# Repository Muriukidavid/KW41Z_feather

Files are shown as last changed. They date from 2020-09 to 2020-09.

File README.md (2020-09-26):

# KW41Z_feather 
 
A feather form factor for BLE, ZigBee or Thread node based on the NXP MKW41Z wireless microcontroller. This is work in progress and a completely untested design as at this point. 

## Preview

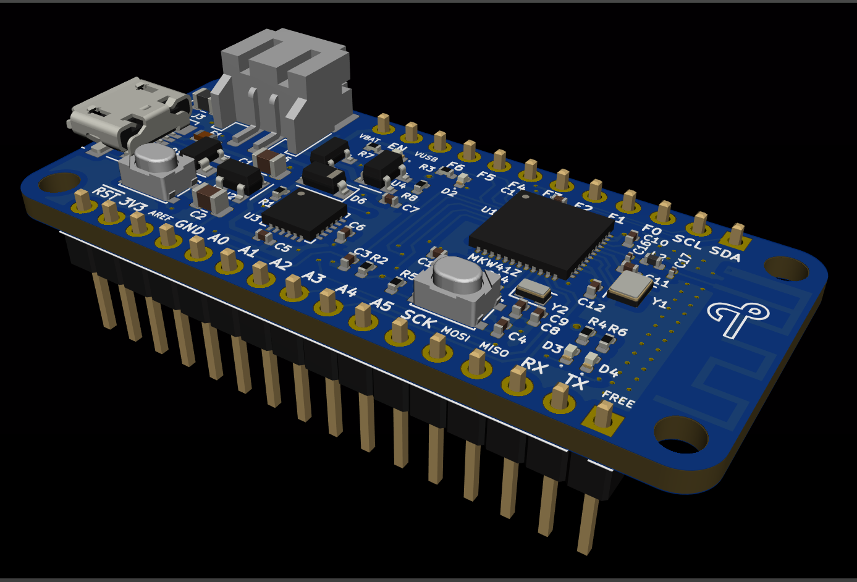
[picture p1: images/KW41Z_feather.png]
PCB Design


## Features 

* Feather header pins (custom mapping due to limited MCU pins)
* NXP MKW41Z Wireless MCU With a PCB antennae
* SWD Debug (using some of the feather header pins)
* USB to UART (CP2104) connected to the MCU UART terminal
* LiPo battery charger (SL4054ST25P) with a standard battery connector
* On board 5V to 3.3V regulator
* RTC oscillator
* Reset and user buttons
* Indicator LEDs (One user LED, two BLE activity LEDs) 

## Planned 

* Add U.FL connector for external antennae with a series selection resistor
* Add on-board SD card connector (back side)

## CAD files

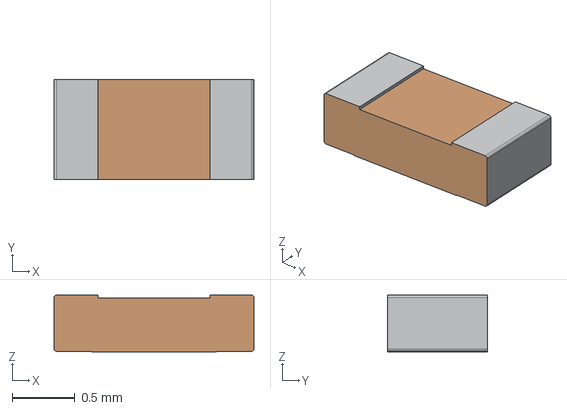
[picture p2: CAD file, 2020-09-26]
3D_Models/SF-0603F.step
1.60 x 0.8 x 0.455 mm

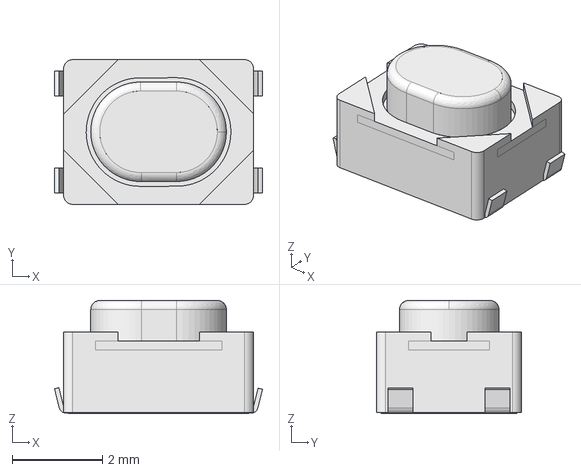
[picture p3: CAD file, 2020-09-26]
3D_Models/PTS810.step
4.60 x 3.20 x 2.50 mm

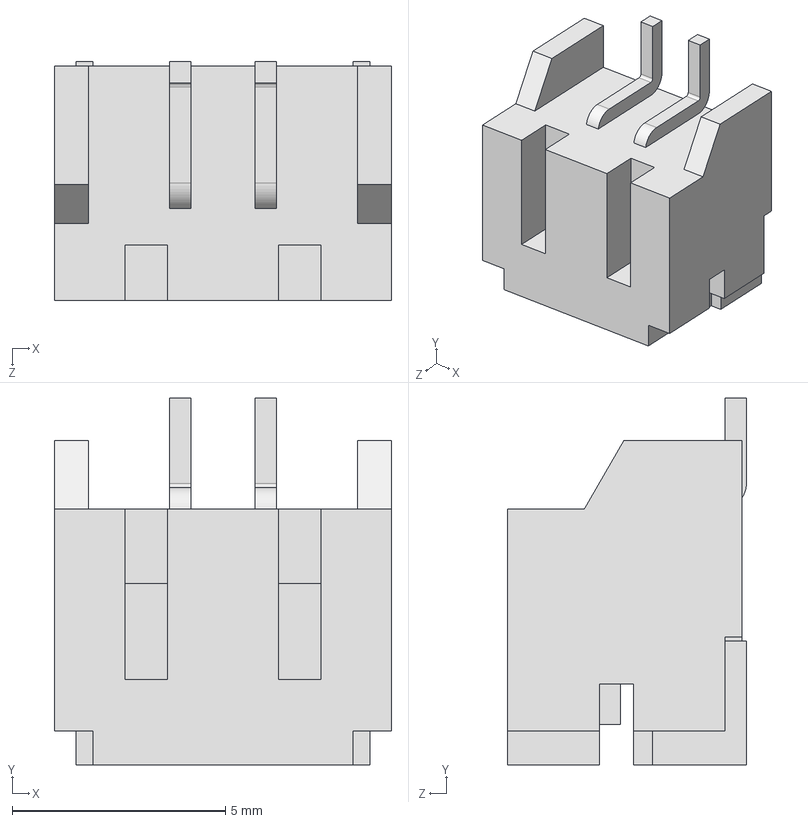
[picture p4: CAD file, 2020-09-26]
3D_Models/S2B-PH-SM4-TB.step
7.90 x 8.60 x 5.60 mm

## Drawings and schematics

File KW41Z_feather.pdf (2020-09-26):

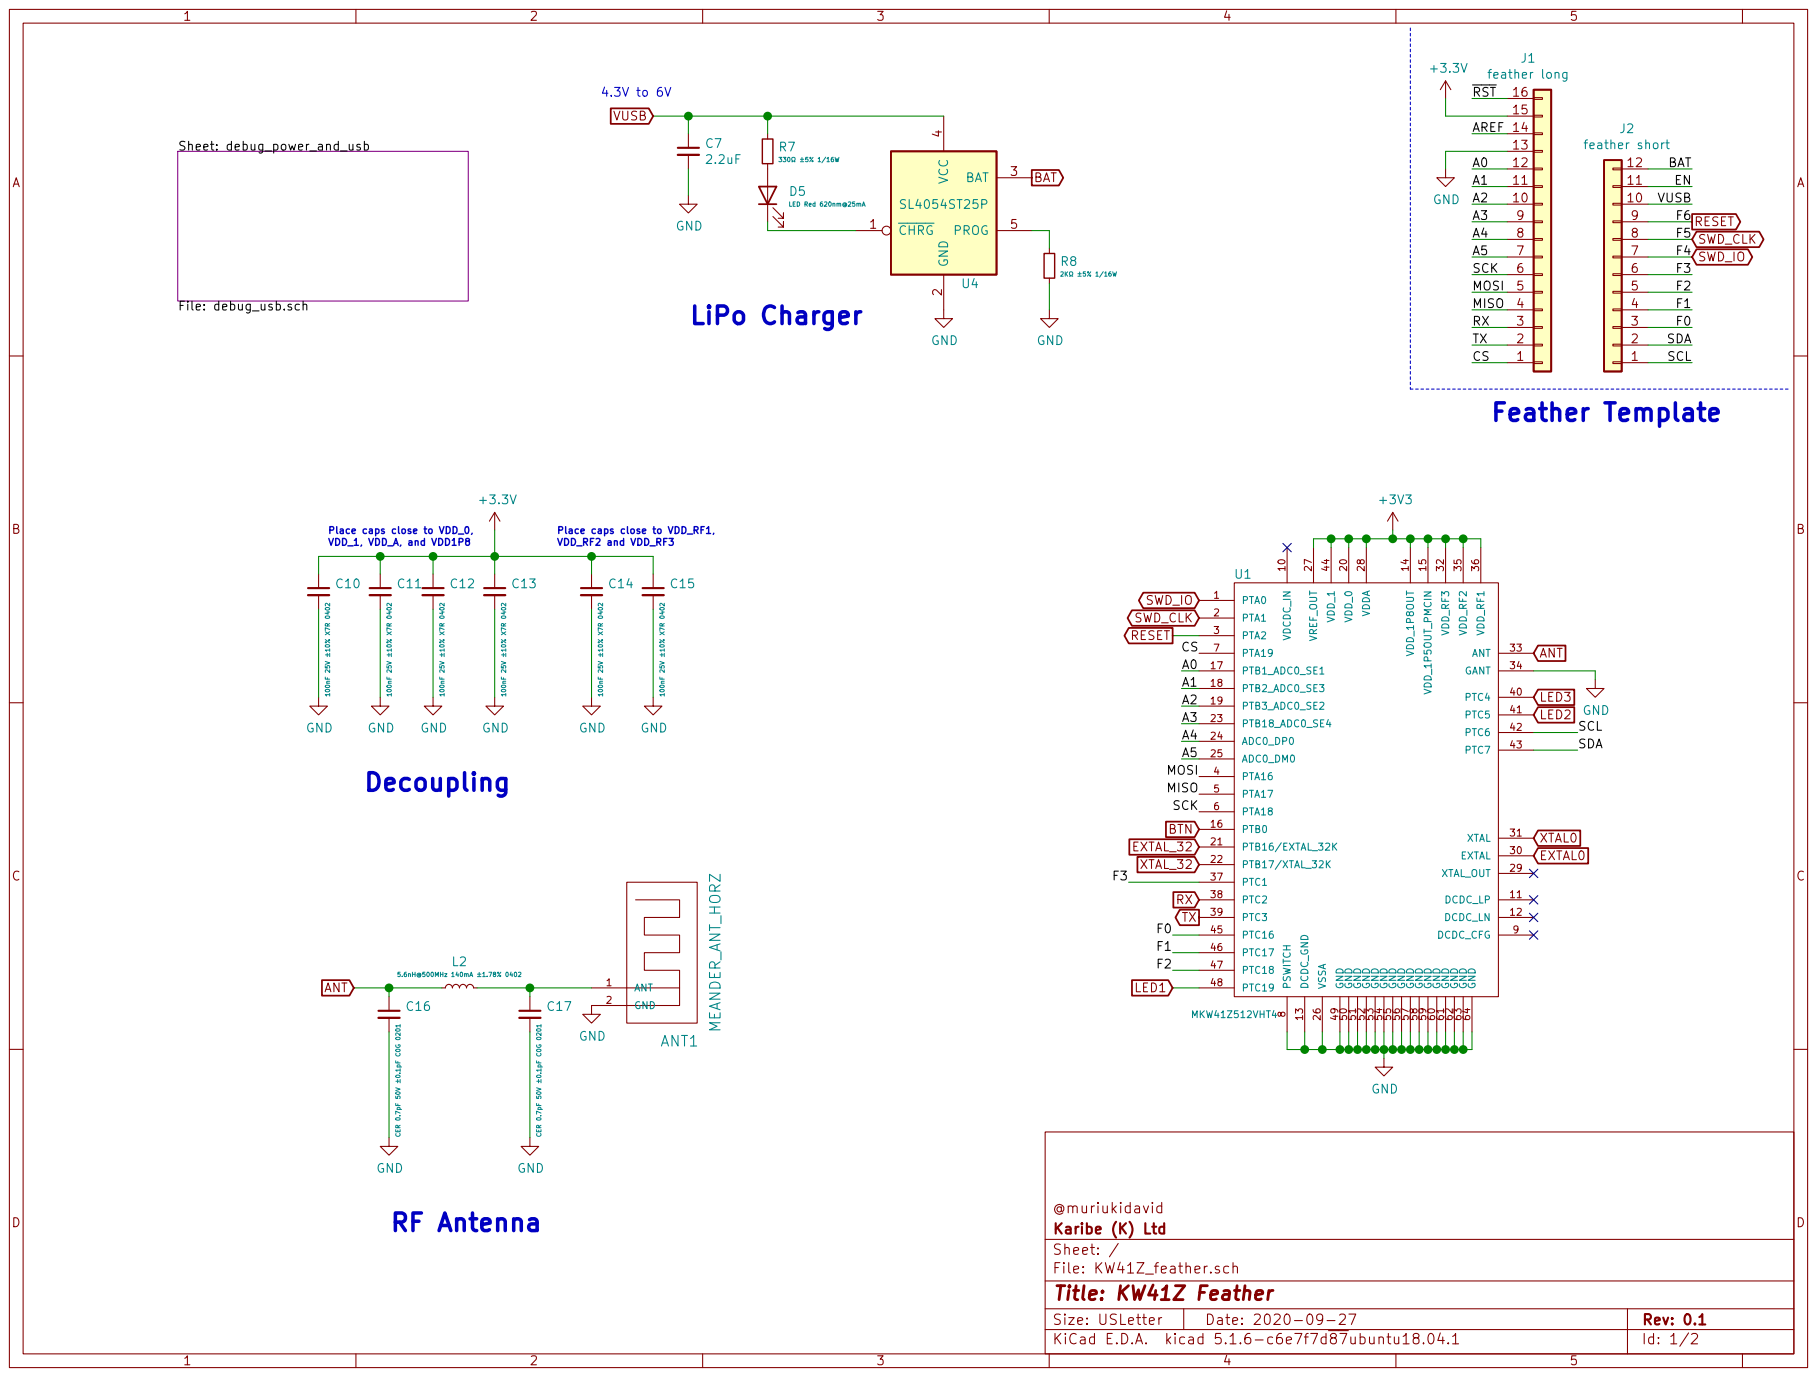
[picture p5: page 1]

RST AREF MOSI SCK

Place caps close to VDD_RF1, VDD_RF2 and VDD_RF3 Place caps close to VDD_0, VDD_1, VDD_A, and VDD1P8 Decoupling

@muriukidavid
File: KW41Z_feather.sch Sheet: / Karibe (K) Ltd

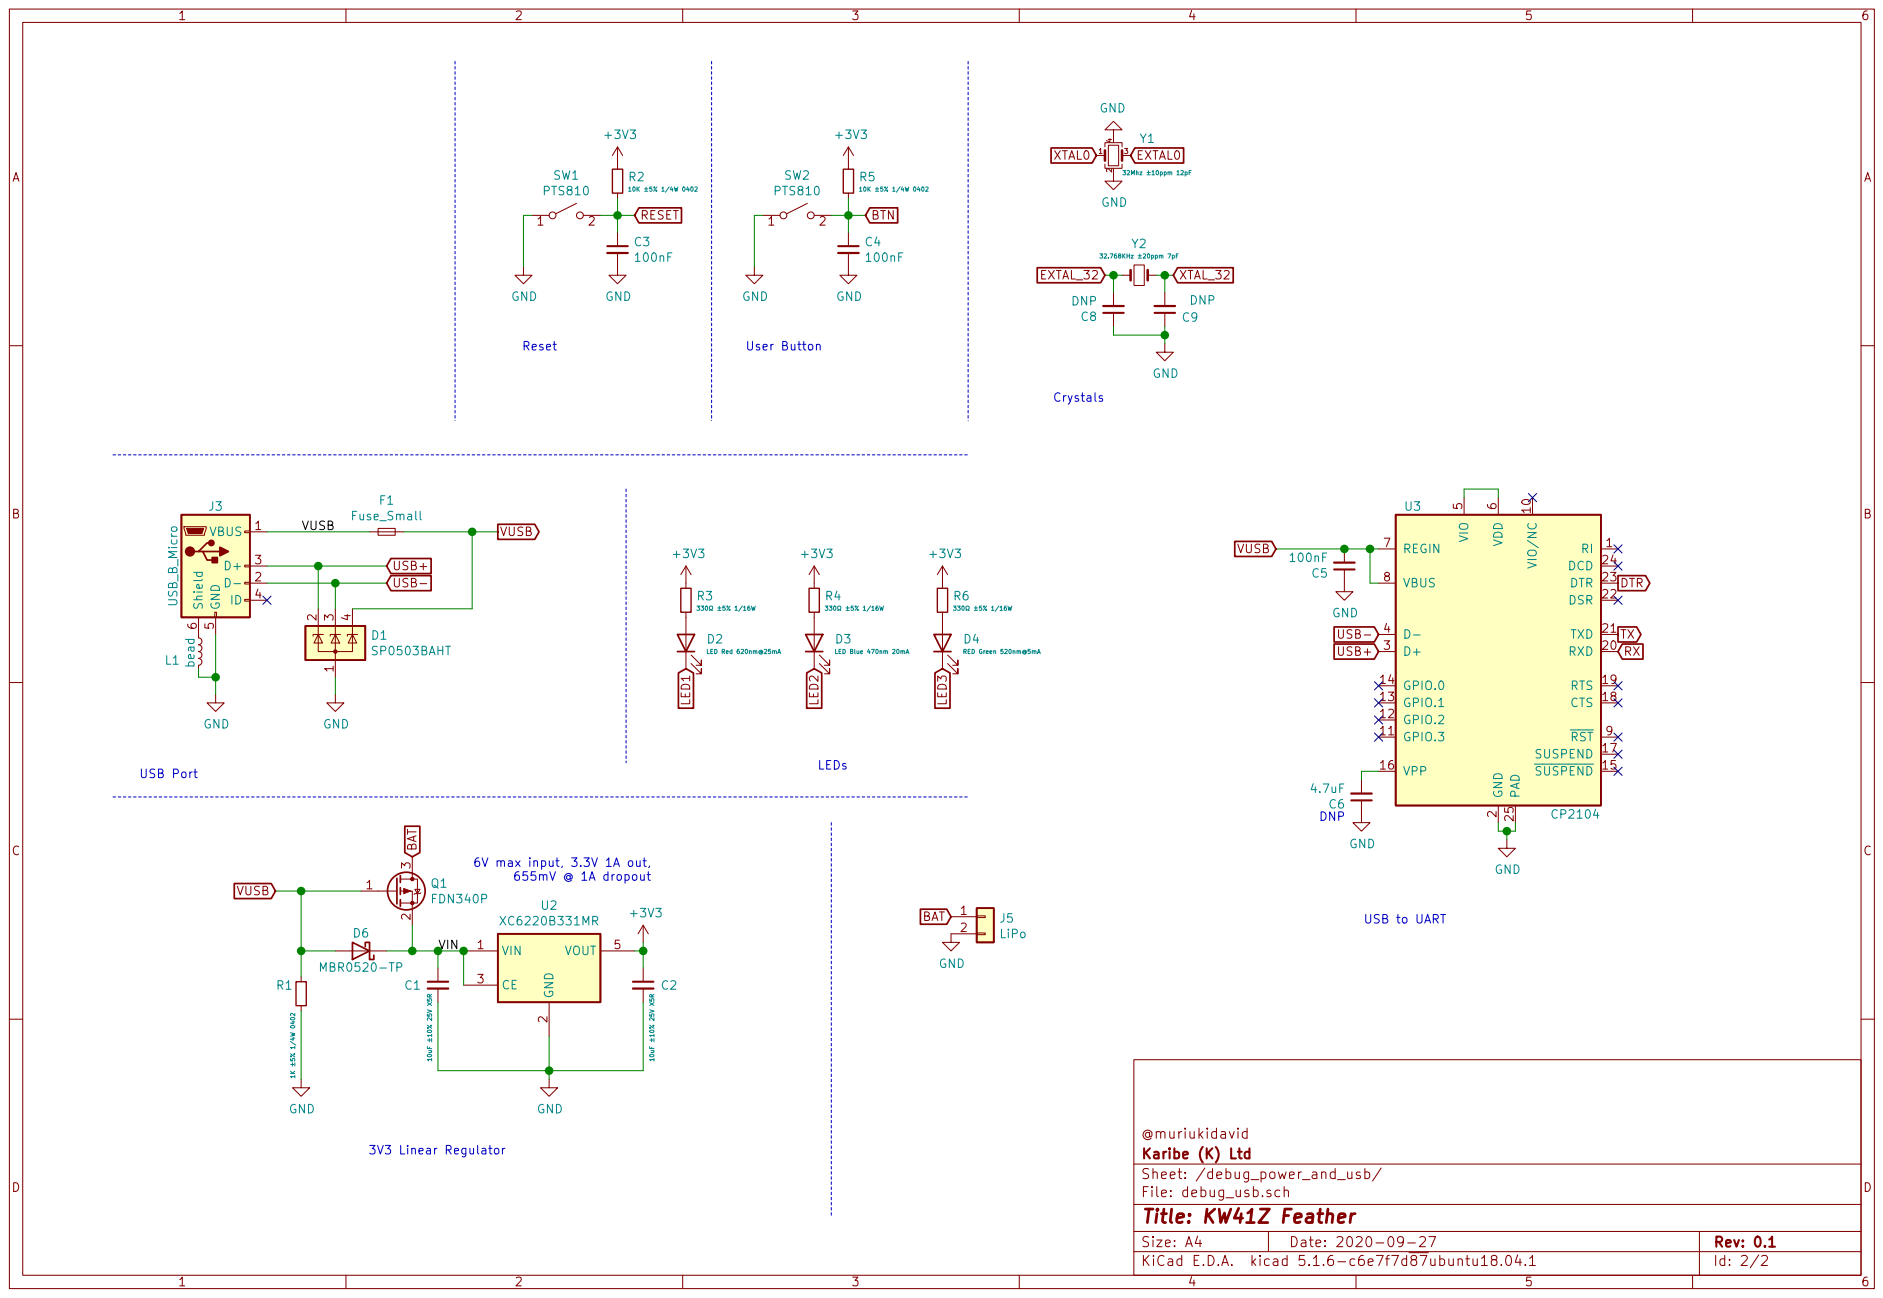
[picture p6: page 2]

2 RXD 20 TXD 21 DSR 22 DTR 23 DCD 24 PAD 25 D+ 3 D- 4 VIO

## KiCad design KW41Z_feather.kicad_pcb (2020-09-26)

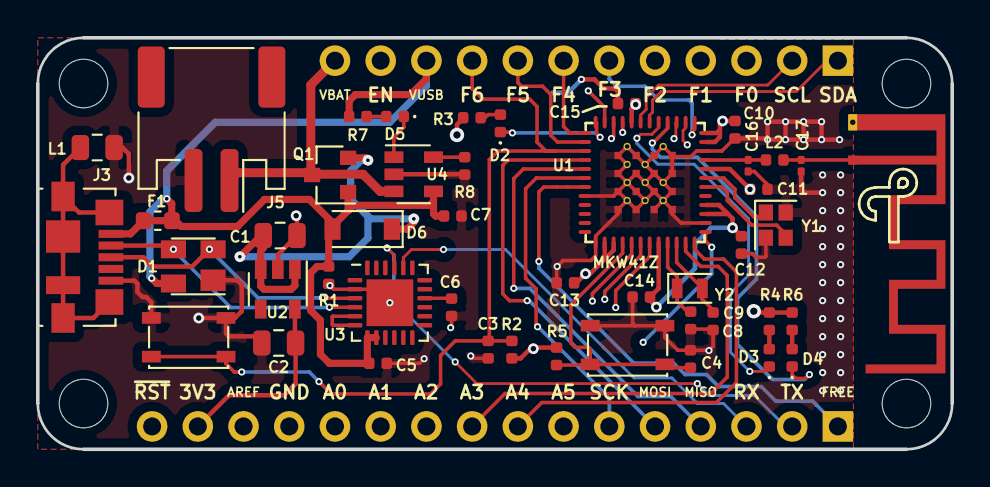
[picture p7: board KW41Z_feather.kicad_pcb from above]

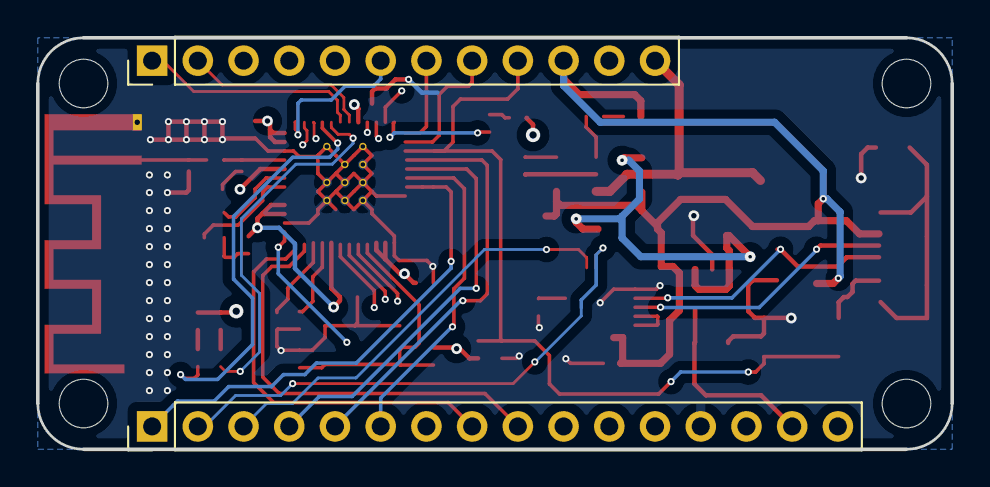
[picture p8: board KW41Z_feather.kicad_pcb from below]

Board: 4 copper layers, 50.8 x 22.9 mm, 48 parts (2 on the bottom side), 47 nets.

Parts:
ANT1: MEANDER_ANT_HORZ; Texas_SWRA117D_2.4GHz_Right
C1, C2: 10uF ±10% 25V X5R; C_0805_2012Metric
C3, C4, C5: 100nF; C_0402_1005Metric
C6: 4.7uF; C_0402_1005Metric
C7: 2.2uF; C_0402_1005Metric
C8, C9: DNP; C_0402_1005Metric
C10, C11, C12, C13, C14, C15: 100nF 25V ±10% X7R 0402; C_0402_1005Metric
C16, C17: CER 0.7pF 50V ±0.1pF C0G 0201; C_0201_0603Metric
D1: SP0503BAHT; SOT-143
D2, D5: LED Red 620nm@25mA; LED_0402_1005Metric
D3: LED Blue 470nm 20mA; LED_0402_1005Metric
D4: RED Green 520nm@5mA; LED_0402_1005Metric
D6: MBR0520-TP; D_SOD-123
F1: Fuse_Small; Fuse_0603_1608Metric
J1: feather long; PinHeader_1x16_P2.54mm_Vertical
J2: feather short; PinHeader_1x12_P2.54mm_Vertical
J3: USB_B_Micro; USB_Micro-B_Molex_47346-0001
J5: LiPo; JST_PH_S2B-PH-SM4-TB_1x02-1MP_P2.00mm_Horizontal
L1: bead; L_0805_2012Metric
L2: 5.6nH@500MHz 140mA ±1.78% 0402; L_0402_1005Metric
Q1: FDN340P; SOT-23
R1: 1K ±5% 1/4W 0402; R_0402_1005Metric
R2, R5: 10K ±5% 1/4W 0402; R_0402_1005Metric
R3, R4, R6, R7: 330Ω ±5% 1/16W; R_0402_1005Metric
R8: 2KΩ ±5% 1/16W; R_0402_1005Metric
SW1, SW2: PTS810; SW_SPST_PTS810
U1: MKW41Z512VHT4; MKW41Z512VHT4_A
U2: XC6220B331MR; SOT-23-5
U3: CP2104; QFN-24-1EP_4x4mm_P0.5mm_EP2.6x2.6mm
U4: SL4054ST25P; SOT-23-5
Y1: 32Mhz ±10ppm 12pF; Crystal_SMD_2016-4Pin_2.0x1.6mm
Y2: 32.768KHz ±20ppm 7pF; Crystal_SMD_2012-2Pin_2.0x1.2mm

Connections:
+3V3: C2.1, C10.1, C11.1, C12.1, C13.1, C14.1, C15.1, J1.15, R2.1, R3.1, R4.1, R5.1, R6.1, U1.14, U1.15, U1.20, U1.27, U1.28, U1.32, U1.35, U1.36, U1.44, U2.5
/A0: J1.12, U1.17
/A1: J1.11, U1.18
/A2: J1.10, U1.19
/A3: J1.9, U1.23
/A4: J1.8, U1.24
/A5: J1.7, U1.25
/CS: J1.1, U1.7
/F0: J2.3, U1.45
/F1: J2.4, U1.46
/F2: J2.5, U1.47
/F3: J2.6, U1.37
/MISO: J1.4, U1.5
/MOSI: J1.5, U1.4
/SCK: J1.6, U1.6
/SCL: J2.1, U1.42
/SDA: J2.2, U1.43
/debug_power_and_usb/VIN: C1.1, D6.1, Q1.2, U2.1, U2.3
ANT: C16.1, L2.1, U1.33
BAT: J2.12, J5.1, Q1.3, U4.3
BTN: C4.1, R5.2, SW2.2, U1.16
EXTAL0: U1.30, Y1.3
EXTAL_32: C8.2, U1.21, Y2.1
GND: ANT1.2, C1.2, C2.2, C3.2, C4.2, C5.1, C6.1, C7.2, C8.1, C9.1, C10.2, C11.2, C12.2, C13.2, C14.2, C15.2, C16.2, C17.2, D1.1, J1.13, J3.5, J5.2, L1.2, R1.2, R8.2, SW1.1, SW2.1, U1.8, U1.13, U1.26, U1.34, U1.49, U1.50, U1.51, U1.52, U1.53, U1.54, U1.55, U1.56, U1.57, U1.58, U1.59, U1.60, U1.61, U1.62, U1.63, U1.64, U2.2, U3.2, U3.25, U4.2, Y1.2, Y1.4
LED1: D2.1, U1.48
LED2: D3.1, U1.41
LED3: D4.1, U1.40
unnamed: ANT1.1, C17.1, L2.2
unnamed: C6.2, U3.16
unnamed: D2.2, R3.2
unnamed: D3.2, R4.2
unnamed: D4.2, R6.2
unnamed: D5.1, U4.1
unnamed: D5.2, R7.2
unnamed: J3.6, L1.1
unnamed: R8.1, U4.5
unnamed: U3.5, U3.6
RESET: C3.1, J2.9, R2.2, SW1.2, U1.3
RX: J1.3, U1.38, U3.20
SWD_CLK: J2.8, U1.2
SWD_IO: J2.7, U1.1
TX: J1.2, U1.39, U3.21
USB+: D1.2, J3.3, U3.3
USB-: D1.3, J3.2, U3.4
VUSB: C5.2, C7.1, D1.4, D6.2, F1.1, F1.2, J2.10, J3.1, Q1.1, R1.1, R7.1, U3.7, U3.8, U4.4
XTAL0: U1.31, Y1.1
XTAL_32: C9.2, U1.22, Y2.2
